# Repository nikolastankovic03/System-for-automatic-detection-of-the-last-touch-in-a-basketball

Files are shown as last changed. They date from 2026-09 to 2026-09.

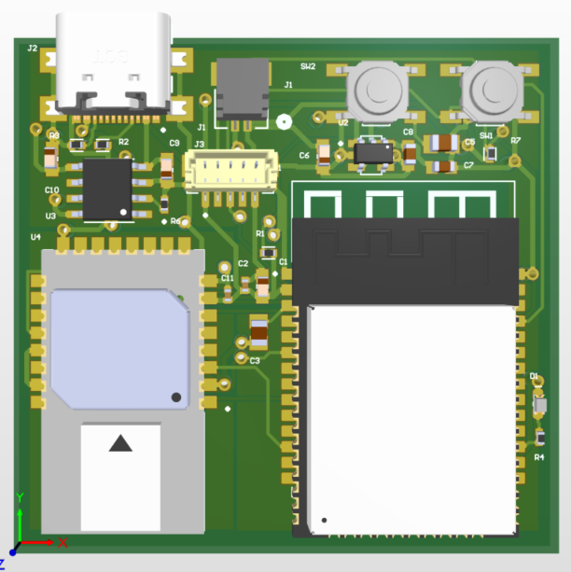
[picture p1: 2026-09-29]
Images/PCB_Player/3Д_Дрес.png

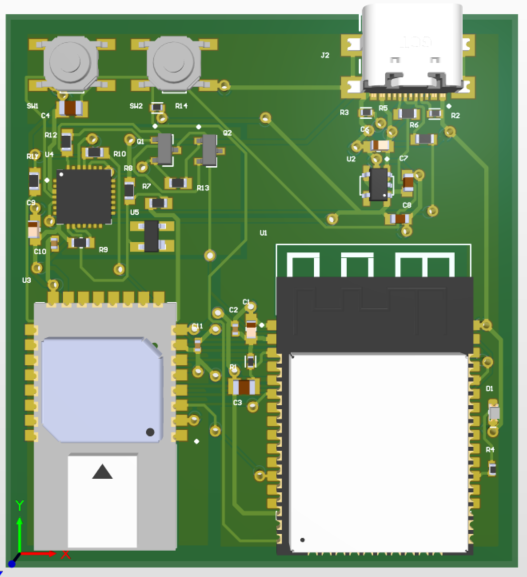
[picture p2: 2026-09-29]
Images/PCB_tabla/3Д_табла.png

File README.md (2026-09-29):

# System-for-automatic-detection-of-the-last-touch-in-a-basketball
The main goal of this work is the design of a system for automatic detection of the last contact with the ball using UWB localization, with precise identification of the player who last touched the ball. The final system architecture includes dedicated printed circuit boards designed for the sensor module inside the ball, the wearable player module, and the stationary module mounted on the backboard structure, while the functionality of the basic algorithms for contact detection, distance measurement, and data transmission was experimentally verified using a laboratory prototype based on available development modules.In addition to the hardware component, a significant part of the work involves the development of a software application for the graphical display and real-time monitoring of events. The application provides an immediate overview of which player, identified by a unique ID, was the last to touch the basketball. The software application consists of a central table displaying all registered contacts, drop-down menus for quick team selection and monitoring of active players, as well as an interactive Start/Stop control system. The Stop button prevents further incoming data from being recorded in the table when the ball leaves the court, thereby preventing irrelevant contacts occurring outside the game from being registered. The Start button reactivates data acquisition when the game resumes.

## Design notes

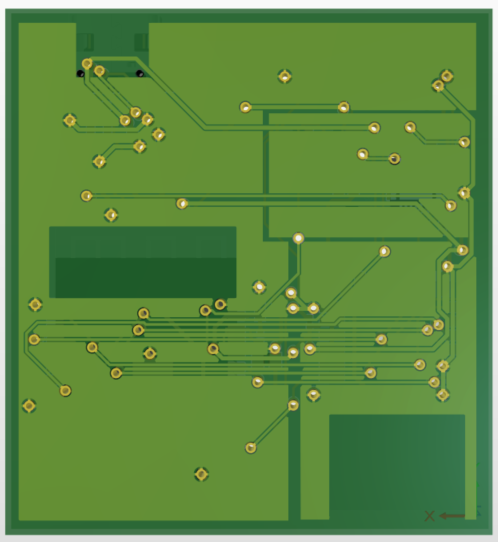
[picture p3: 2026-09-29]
Images/PCB_tabla/3Д_задња_табла.png

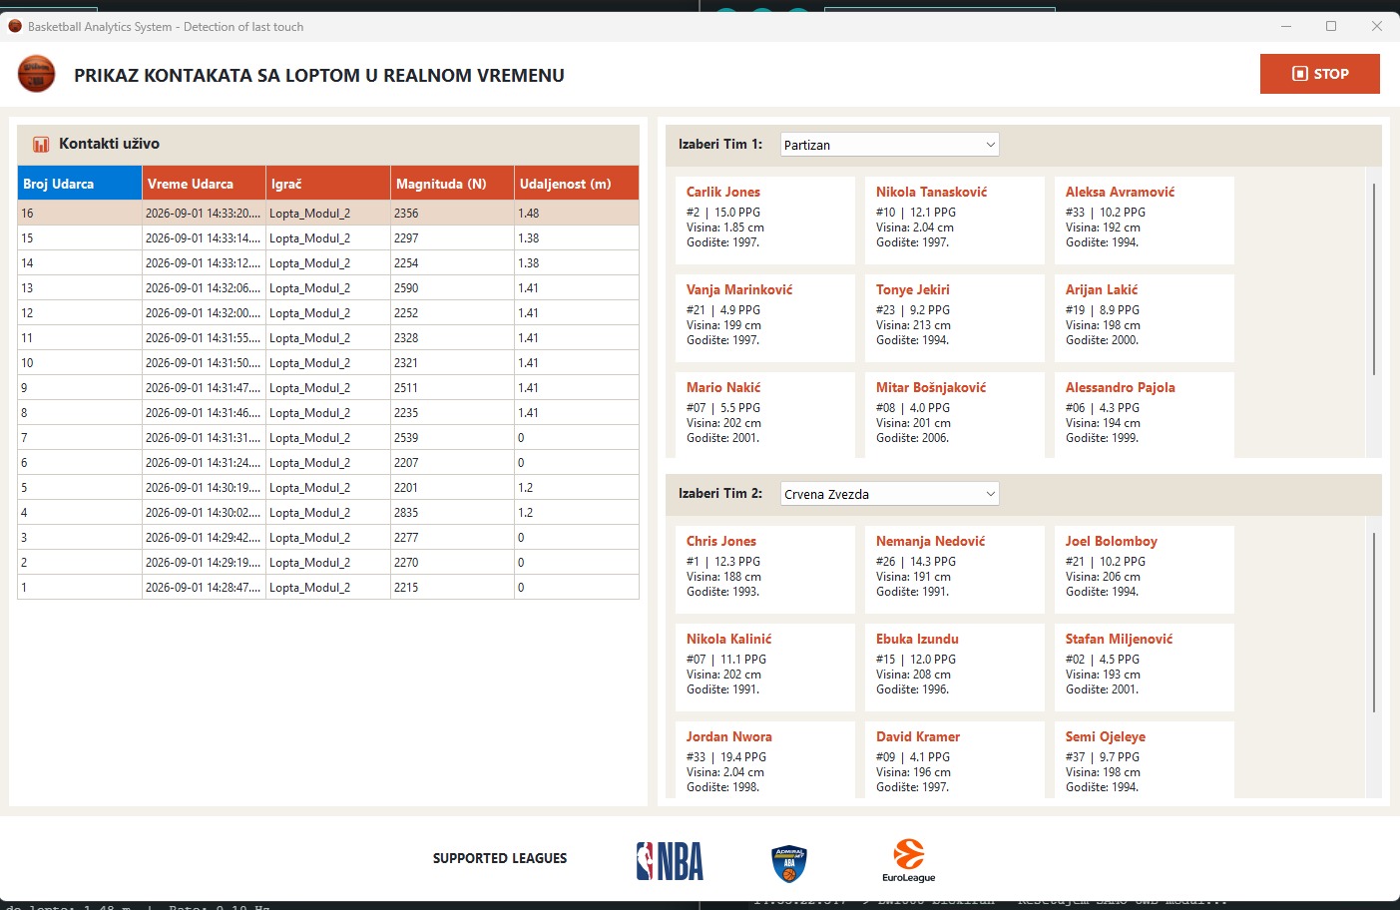
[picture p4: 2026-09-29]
Images/Desktop Aplication/tabela.jpeg

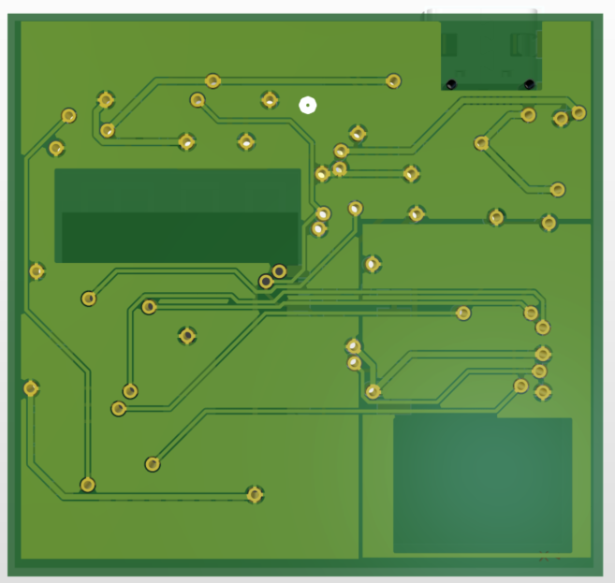
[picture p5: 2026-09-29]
Images/PCB_Player/3Д_Задњастреана_дрес.png

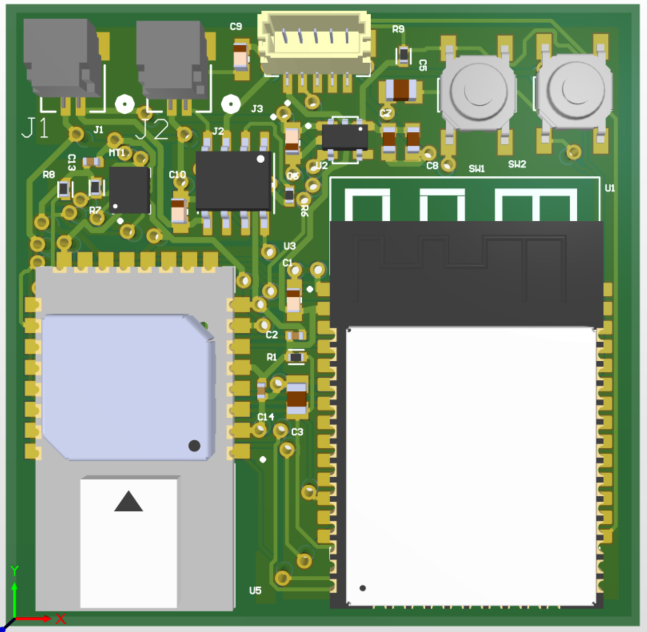
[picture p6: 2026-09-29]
Images/PCB_Ball/3д_лоптапредња_страна.png

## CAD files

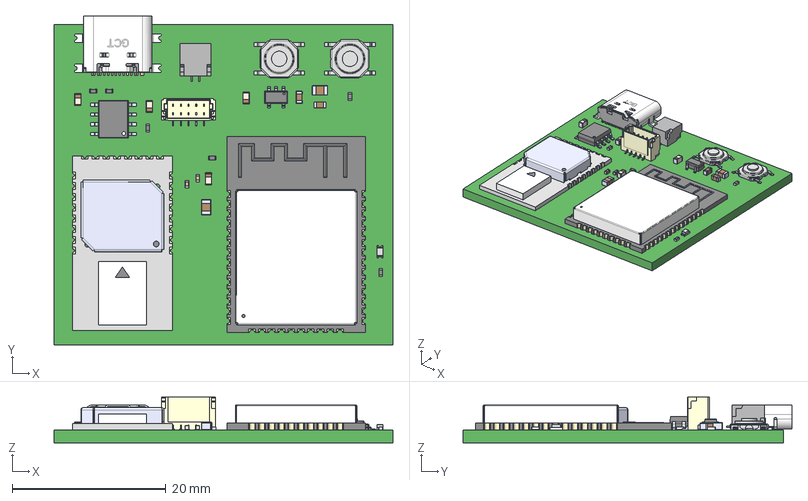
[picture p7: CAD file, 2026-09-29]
PCB_Dres/PCB_Dres.step
44.1 x 42.8 x 5.94 mm
USB4110-GF-A_revB(1) MF
SM02B-SRSS-TB__LF__SN__RGB8421504

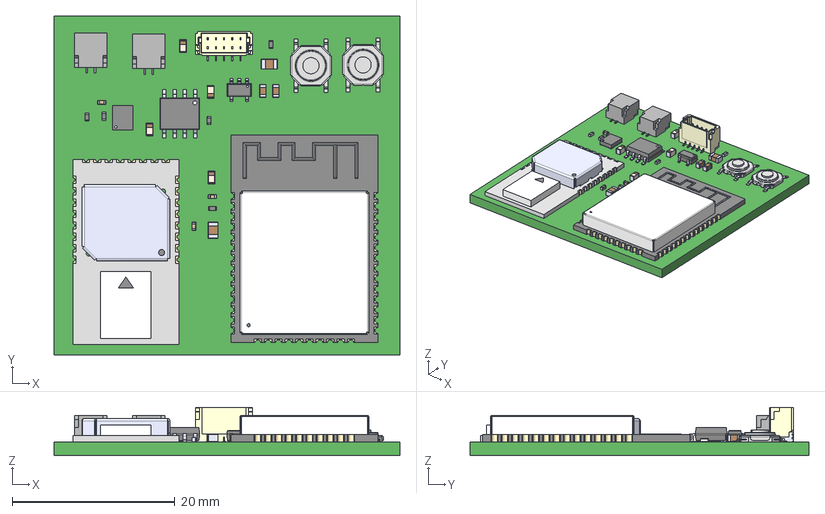
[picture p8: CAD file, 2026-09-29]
PCB_Lopta/PCB_Ball.step
42.4 x 41.6 x 5.94 mm
SM02B-SRSS-TB__LF__SN__RGB8421504 x 2

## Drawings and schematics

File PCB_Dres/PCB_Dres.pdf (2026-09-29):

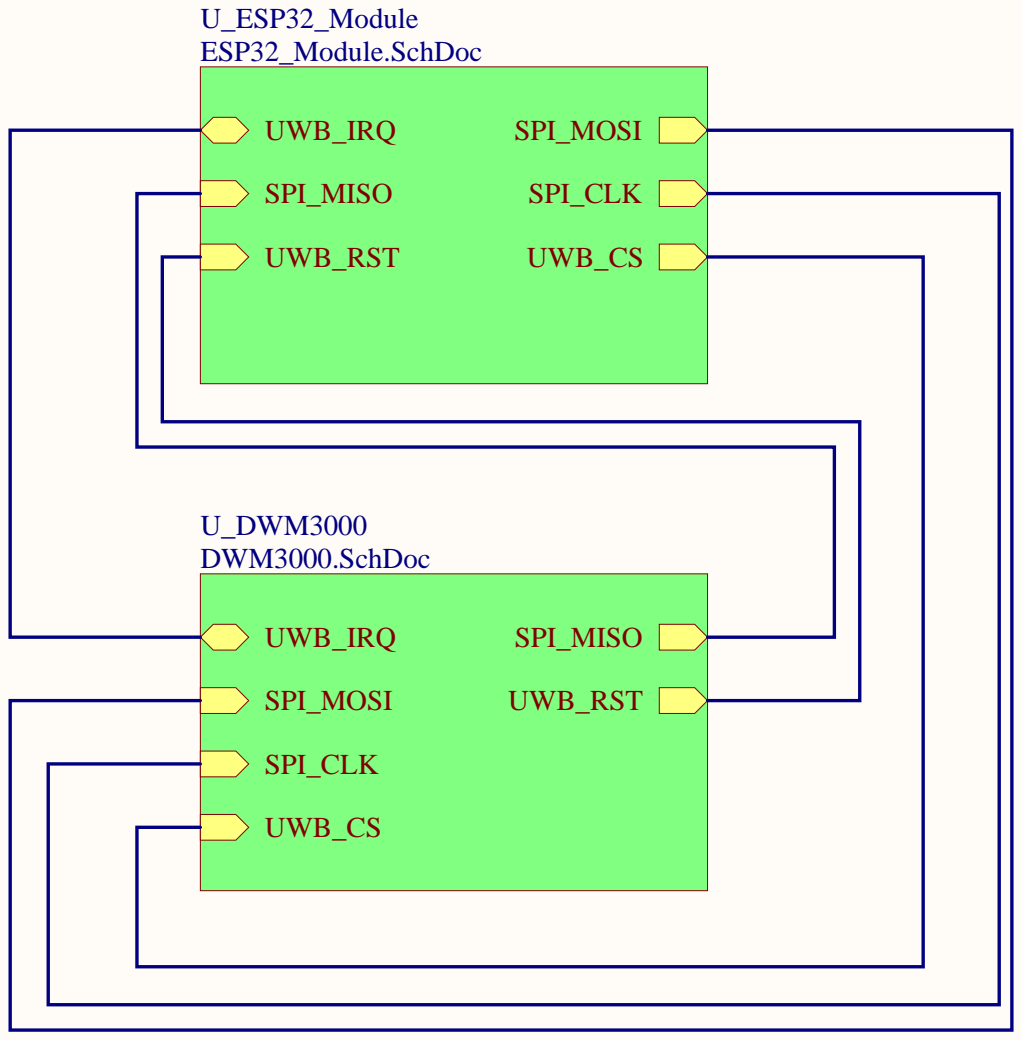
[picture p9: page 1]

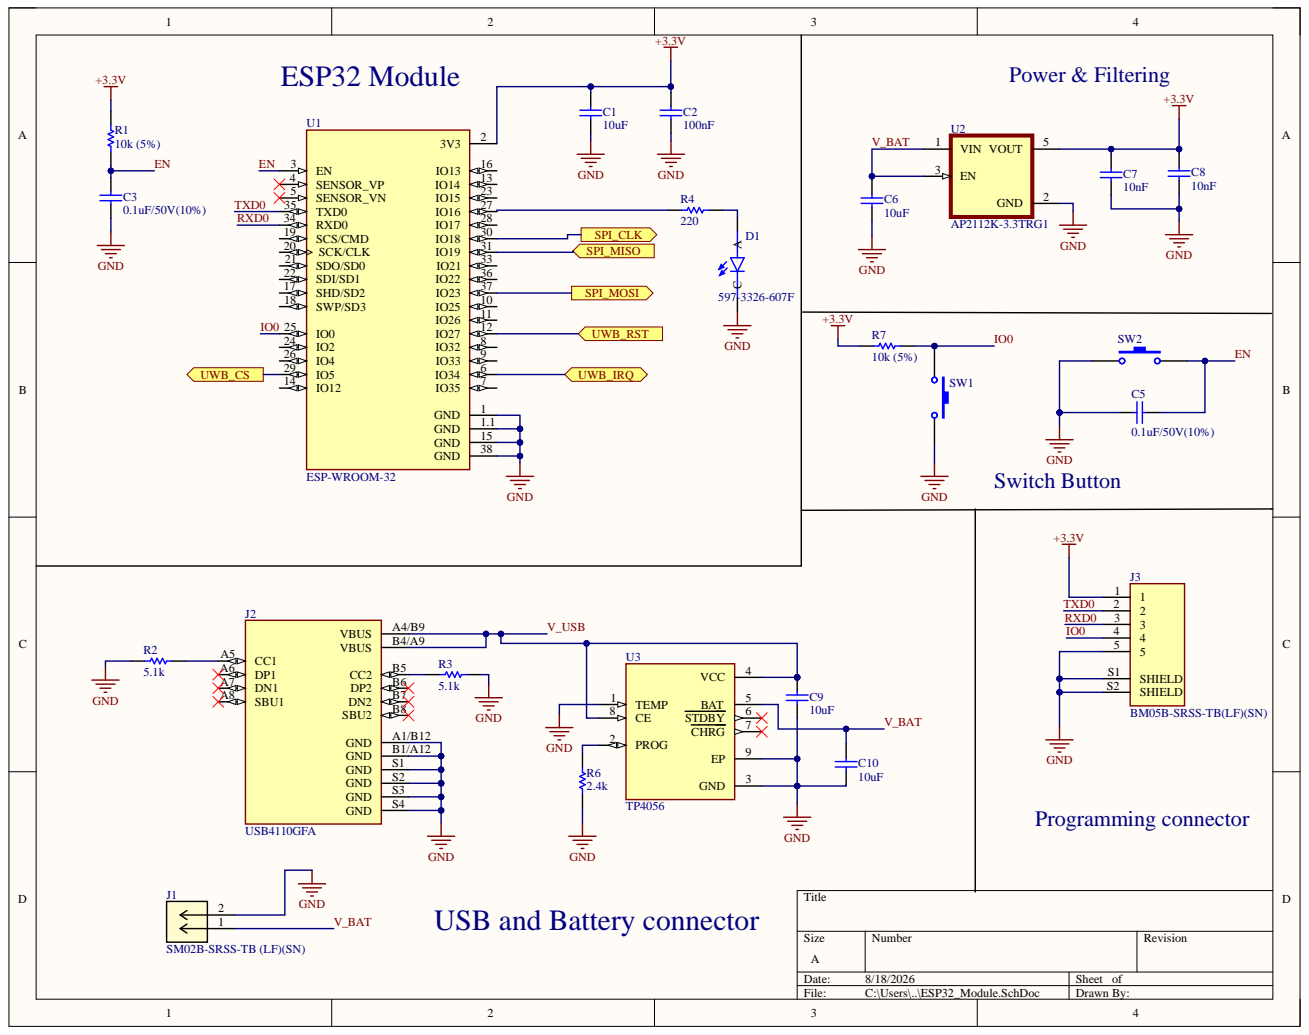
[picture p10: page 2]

BM05B-SRSS-TB(LF)(SN)

USB and Battery connector

SM02B-SRSS-TB (LF)(SN)

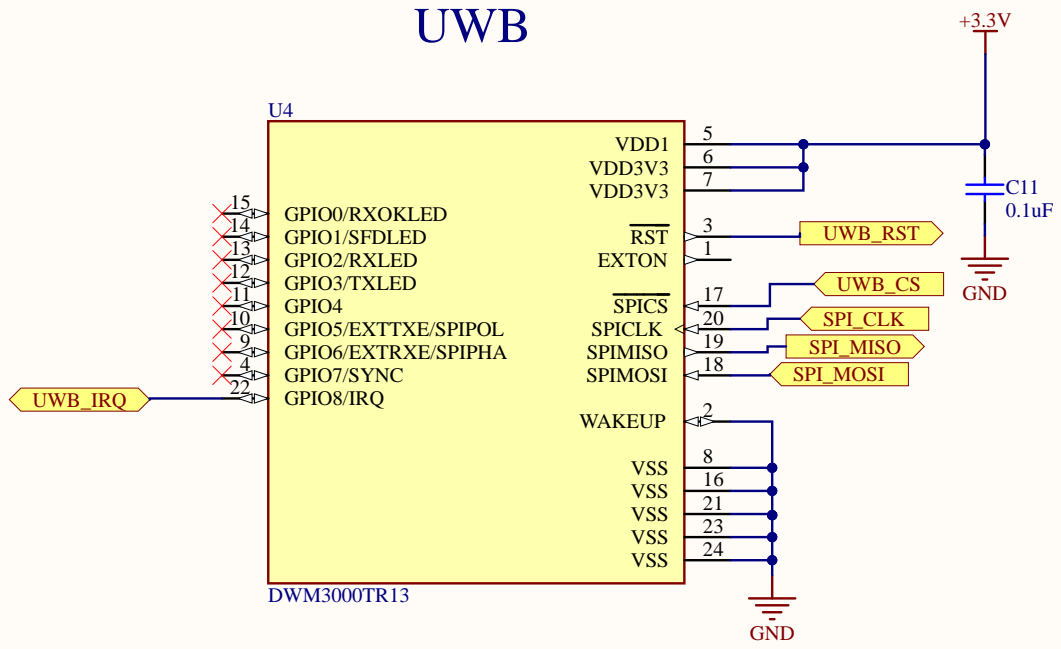
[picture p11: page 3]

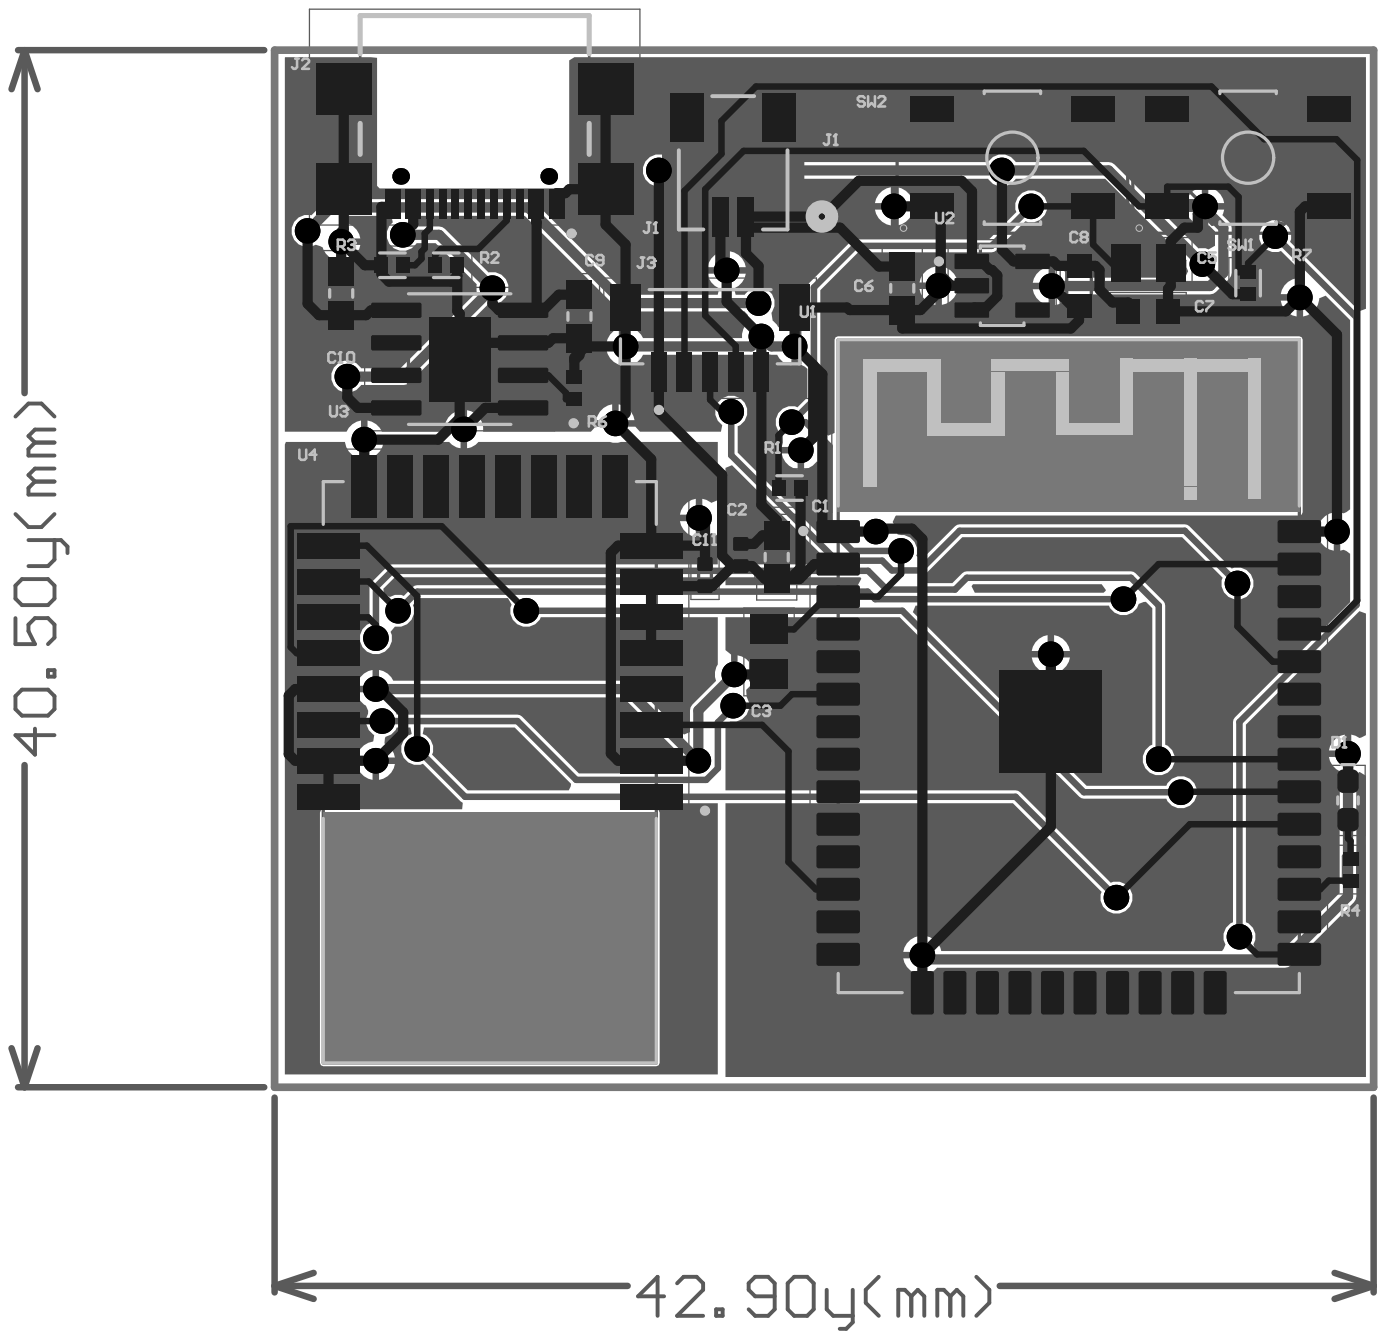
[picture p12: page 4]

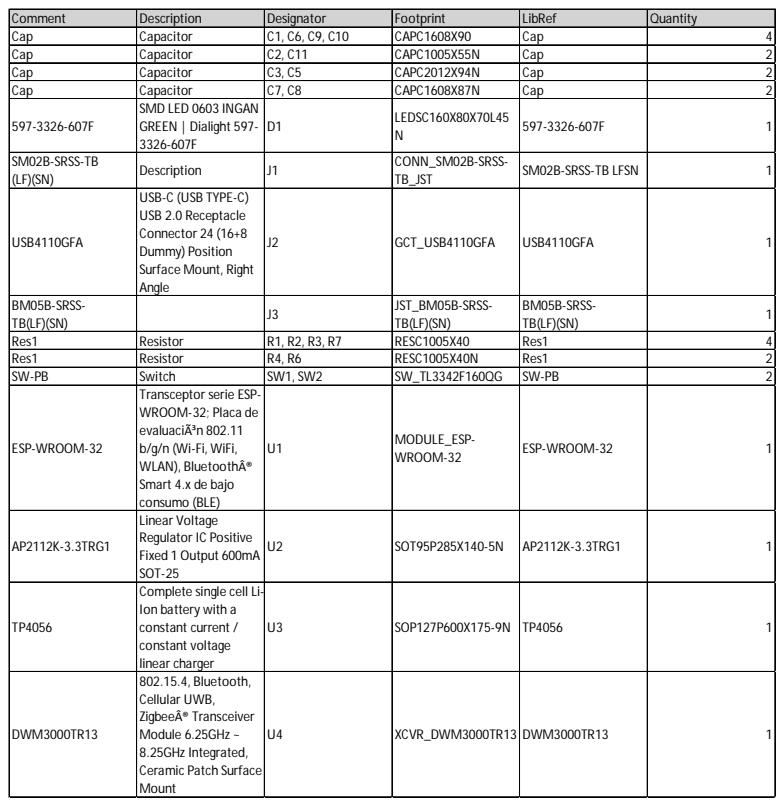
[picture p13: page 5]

Comment | Description | Designator | Footprint | LibRef | Quantity
Cap | Capacitor | C1, C6, C9, C10 | CAPC1608X90 | Cap | 4
Cap | Capacitor | C2, C11 | CAPC1005X55N | Cap | 2
Cap | Capacitor | C3, C5 | CAPC2012X94N | Cap | 2
Cap | Capacitor | C7, C8 | CAPC1608X87N | Cap | 2
597-3326-607F | SMD LED 0603 INGAN GREEN | Dialight 597-3326-607F | D1 | LEDSC160X80X70L45 N | 597-3326-607F | 1

SM02B-SRSS-TB (LF)(SN) | Description | J1 | CONN_SM02B-SRSS-TB_JST | SM02B-SRSS-TB LFSN | 1

USB4110GFA | USB-C (USB TYPE-C) USB 2.0 Receptacle Connector 24 (16+8 Dummy) Position Surface Mount, Right Angle | J2 | GCT_USB4110GFA | USB4110GFA | 1

BM05B-SRSS-TB(LF)(SN) | | J3 | JST_BM05B-SRSS-TB(LF)(SN) | BM05B-SRSS-TB(LF)(SN) | 1

Res1 | Resistor | R1, R2, R3, R7 | RESC1005X40 | Res1 | 4
Res1 | Resistor | R4, R6 | RESC1005X40N | Res1 | 2
SW-PB | Switch | SW1, SW2 | SW_TL3342F160QG | SW-PB | 2
ESP-WROOM-32 | Transceptor serie ESP-WROOM-32; Placa de evaluaciÃ³n 802.11 b/g/n (Wi-Fi, WiFi, WLAN), BluetoothÂ® Smart 4.x de bajo consumo (BLE) | U1 | MODULE_ESP-WROOM-32 | ESP-WROOM-32 | 1

AP2112K-3.3TRG1 | Linear Voltage Regulator IC Positive Fixed 1 Output 600mA SOT-25 | U2 | SOT95P285X140-5N | AP2112K-3.3TRG1 | 1

TP4056 | Complete single cell Li-Ion battery with a constant current / constant voltage linear charger | U3 | SOP127P600X175-9N | TP4056 | 1

DWM3000TR13 | 802.15.4, Bluetooth, Cellular UWB, ZigbeeÂ® Transceiver Module 6.25GHz ~ 8.25GHz Integrated, Ceramic Patch Surface Mount | U4 | XCVR_DWM3000TR13 | DWM3000TR13 | 1

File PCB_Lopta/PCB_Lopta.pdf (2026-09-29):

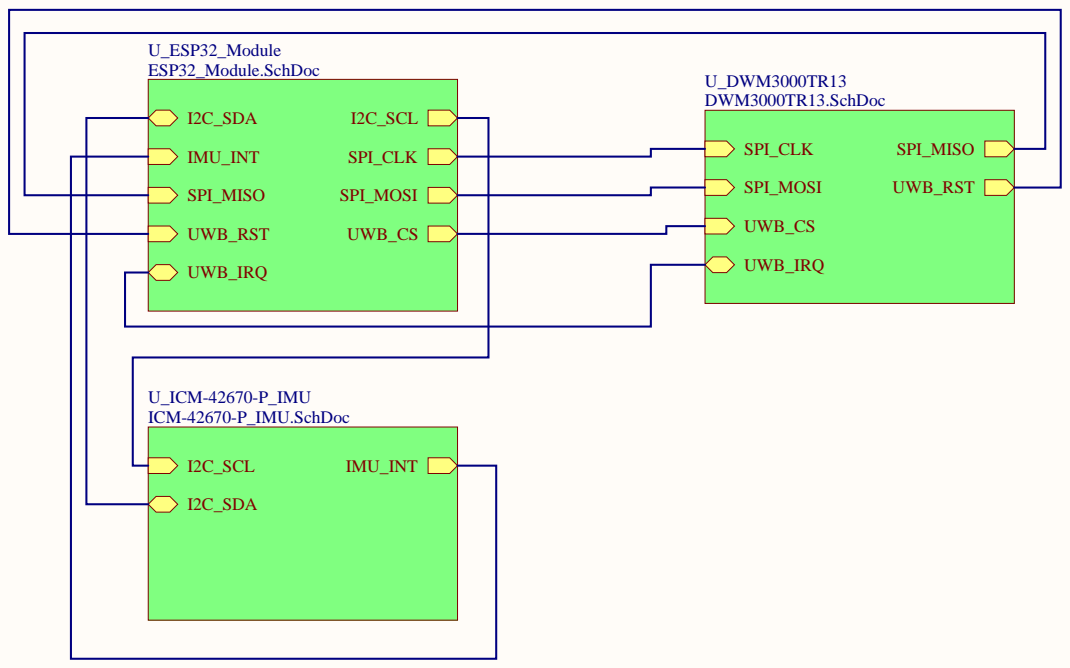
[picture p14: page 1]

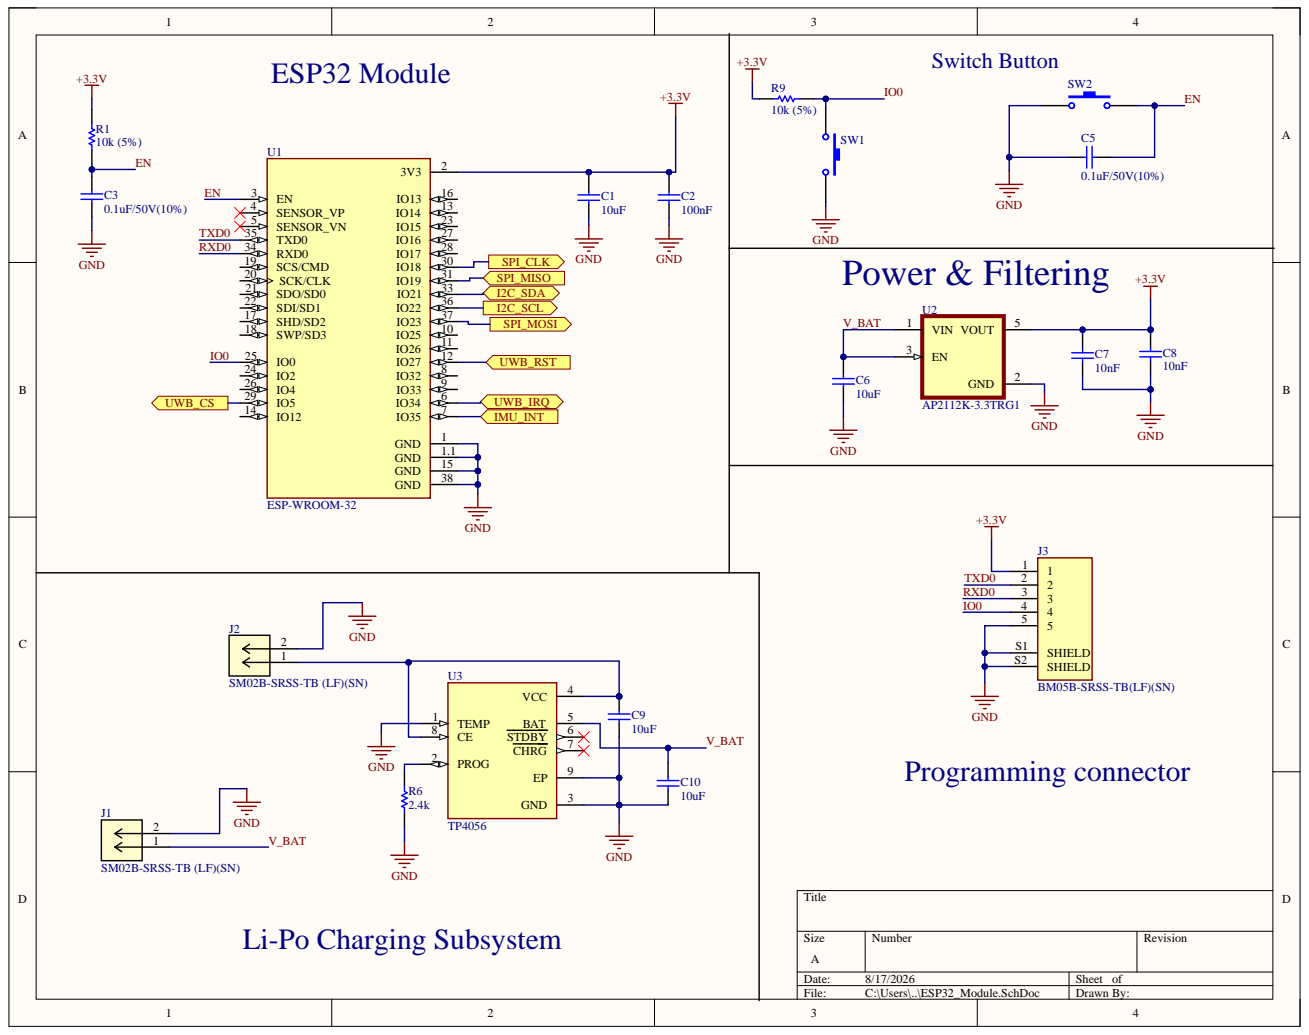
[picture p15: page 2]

SHIELD S1
SHIELD S2

SM02B-SRSS-TB (LF)(SN)

BM05B-SRSS-TB(LF)(SN)

Li-Po Charging Subsystem

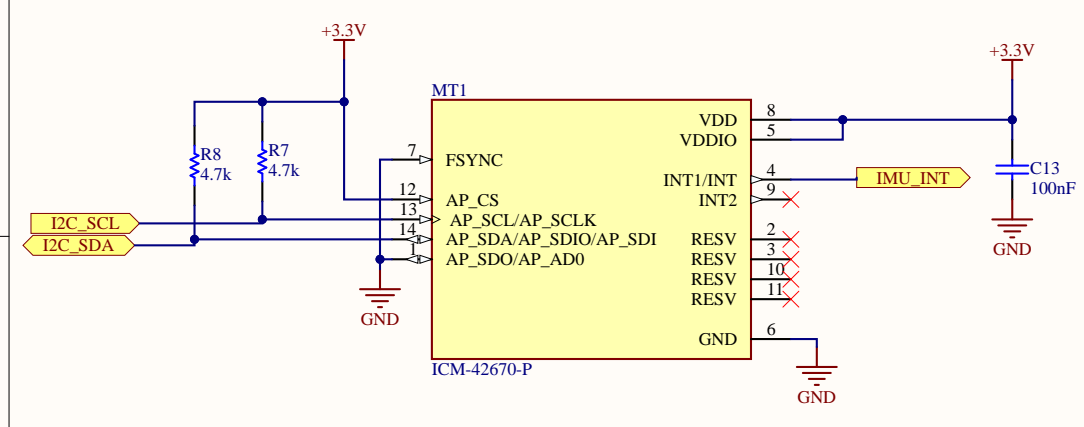
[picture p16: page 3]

AP_CS 12
1 | AP_SCL/AP_SCLK 13 AP_SDA/AP_SDIO/AP_SDI 14

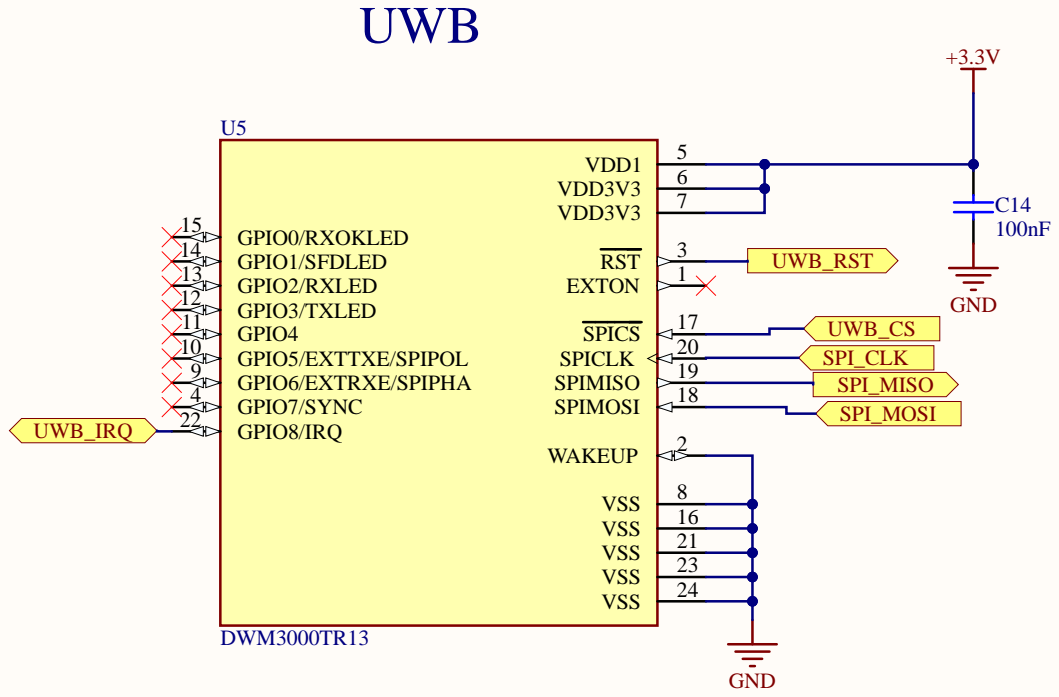
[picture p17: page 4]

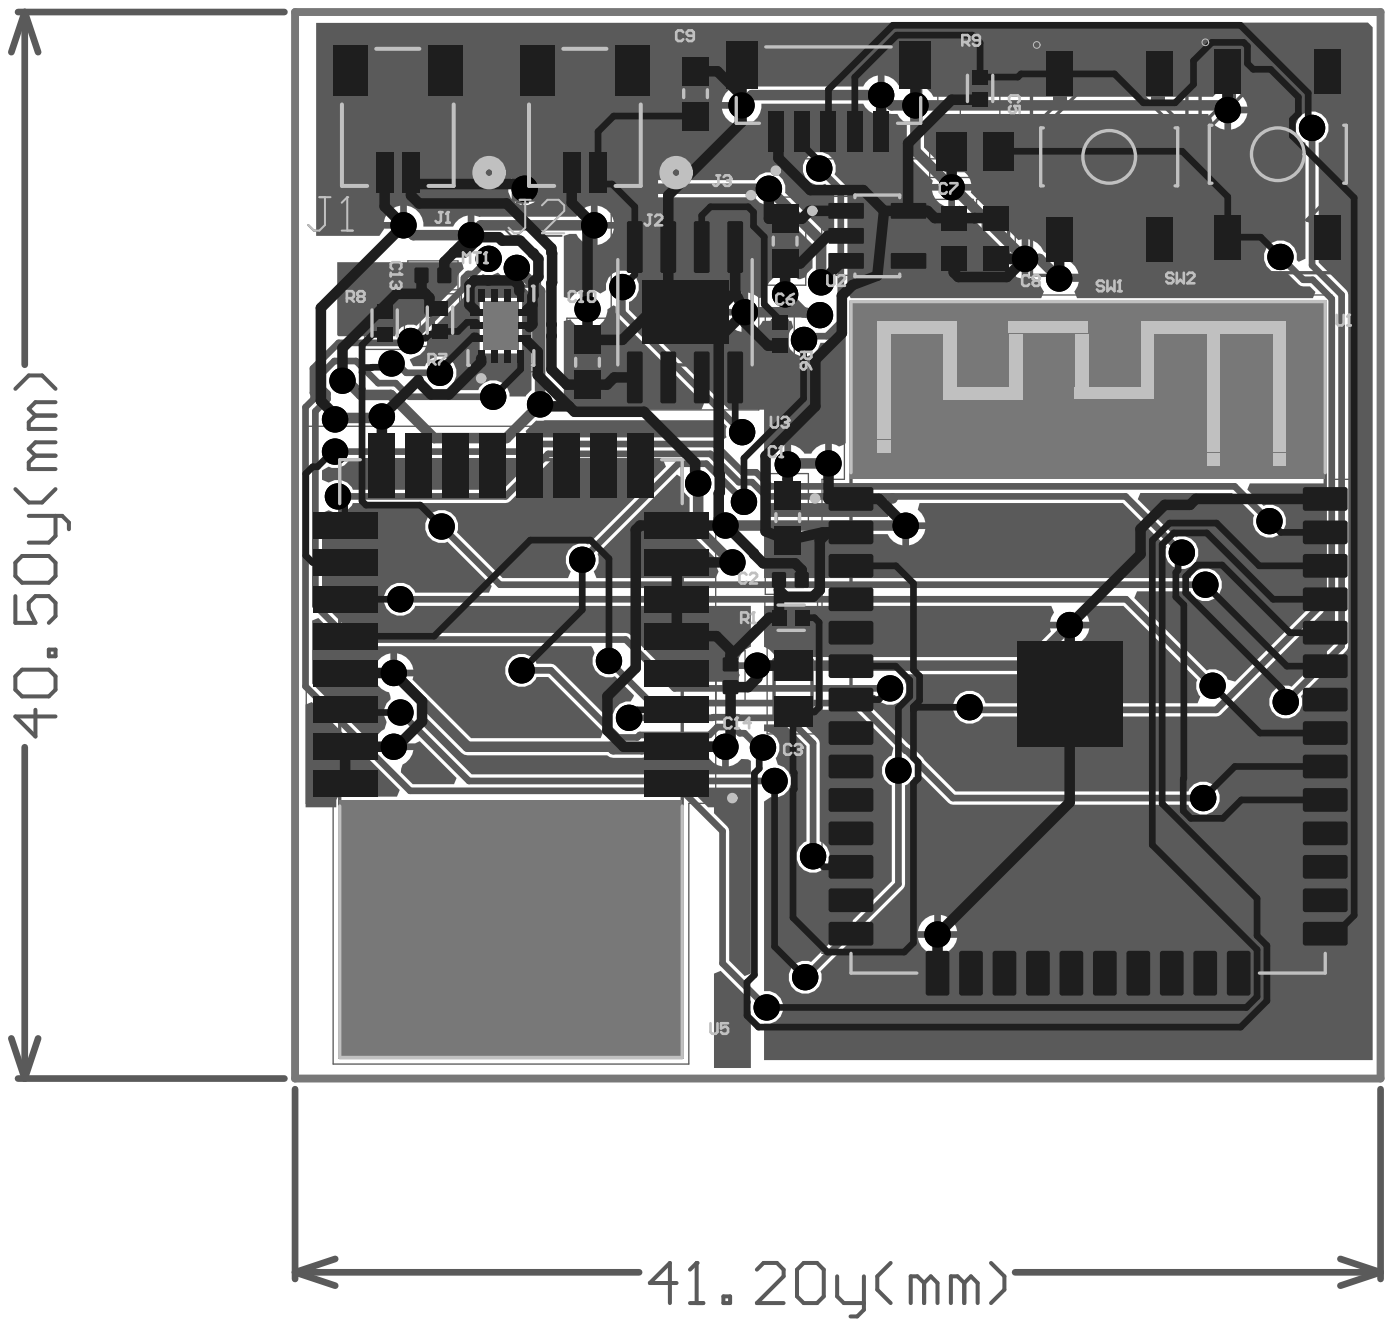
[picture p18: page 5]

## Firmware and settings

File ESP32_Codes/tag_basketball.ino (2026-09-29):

#include <SPI.h>
#include <Wire.h>
#include <WiFi.h>
#include <DW1000.h>
#include <Adafruit_GFX.h>
#include <Adafruit_SH110X.h>
#include <HTTPClient.h>

const char* WIFI_SSID = "XXXXX";
const char* WIFI_PASSWORD = "XXXXXXX";
const char* SERVER_URL = "XXXXXXXXXXXXXXXXXX";
const char* IME_IGRACA = "Lopta_Modul_2";
uint32_t poslednjiPokusajWifi = 0;
const uint32_t WIFI_RETRY_INTERVAL = 10000;

const uint8_t PIN_RST = 4;
const uint8_t PIN_IRQ = 27;
const uint8_t PIN_SS = 5;

#define SCREEN_WIDTH 128
#define SCREEN_HEIGHT 64
Adafruit_SH1106G display(SCREEN_WIDTH, SCREEN_HEIGHT, &Wire, -1);

#define IMU_ADDR 0x68
#define REG_PWR_MGMT0 0x1F
#define REG_ACCEL_DATA_X1 0x0B
#define UDAR_PRAG 2200

#define POLL 0
#define POLL_ACK 1
#define RANGE 2
#define RANGE_REPORT 3
#define RANGE_FAILED 255

volatile byte expectedMsgId = POLL_ACK;
volatile boolean sentAck = false;
volatile boolean receivedAck = false;
volatile byte lastSentMsgId = 255;

DW1000Time timePollSent;
DW1000Time timePollAckReceived;
DW1000Time timeRangeSent;

#define LEN_DATA 16
byte data[LEN_DATA];

uint32_t lastActivity;
uint32_t resetPeriod = 1000;
uint16_t replyDelayTimeUS = 3000;

float lastDistance = 0;
bool haveNewDistance = false;
uint32_t lastPrintTime = 0;
const uint32_t printInterval = 1000;

uint32_t lastOledUpdate = 0;
const uint32_t oledInterval = 200;

uint32_t lastImuRead = 0;
const uint32_t imuInterval = 20;
long zadnjaMagnituda = 0;
int brojUdaraca = 0;

bool udaracUToku = false;
uint32_t vremeZadnjegUdarca = 0;
const uint32_t trajanjeprikazaUdarca = 500;

uint32_t countPollSent = 0;
uint32_t countPollAckRecv = 0;
uint32_t countRangeSent = 0;
uint32_t countRangeReportRecv = 0;
uint32_t countRangeFailedRecv = 0;
uint32_t countProtocolMismatch = 0;
uint32_t countResets = 0;
uint32_t countTransmitCalls = 0;
uint32_t countUnknownMsgId = 0;

void connectWiFi() {
    WiFi.mode(WIFI_STA);
    WiFi.begin(WIFI_SSID, WIFI_PASSWORD);
}

void initUWB() {
    DW1000.begin(PIN_IRQ, PIN_RST);
    DW1000.select(PIN_SS);
    DW1000.newConfiguration();
    DW1000.setDefaults();
    DW1000.setDeviceAddress(2);
    DW1000.setNetworkId(10);
    DW1000.enableMode(DW1000.MODE_LONGDATA_RANGE_LOWPOWER);
    DW1000.commitConfiguration();
    DW1000.attachSentHandler(handleSent);
    DW1000.attachReceivedHandler(handleReceived);
}

void writeRegister(uint8_t reg, uint8_t value) {
    Wire.beginTransmission(IMU_ADDR);
    Wire.write(reg);
    Wire.write(value);
    Wire.endTransmission();
}

void noteActivity() {
    lastActivity = millis();
}

void resetInactive() {
    Serial.println("DW1000 blokiran - Resetujem SAMO UWB modul...");
    countResets++;

    pinMode(PIN_RST, OUTPUT);
    digitalWrite(PIN_RST, LOW);
    delay(10);
    pinMode(PIN_RST, INPUT);
    delay(20);

    initUWB();

    expectedMsgId = POLL_ACK;
    sentAck = false;
    receivedAck = false;

    transmitPoll();
    noteActivity();
}

void posaljiPodatke(long magnituda) {
    if (WiFi.status() != WL_CONNECTED) return;

    detachInterrupt(digitalPinToInterrupt(PIN_IRQ));
    DW1000.idle();

    float slanjeUdaljenosti = haveNewDistance ? lastDistance : 0.0;

    HTTPClient http;
    http.begin(SERVER_URL);
    http.addHeader("Content-Type", "application/json");
    http.setTimeout(1500); 
    
    String jsonPayload = "{\"igrac\":\"" + String(IME_IGRACA) +
                          "\",\"magnituda\":" + String(magnituda) +
                          ",\"udaljenost\":" + String(slanjeUdaljenosti, 2) + "}";
    http.POST(jsonPayload);
    http.end();

    resetInactive();
}

void setup() {
    Serial.begin(115200);
    delay(1000);

    Wire.begin(21, 22);
    delay(100);
    if (!display.begin(0x3C, true)) {
        Serial.println("OLED nije pronadjen!");
    }
    display.clearDisplay();
    display.setTextColor(SH110X_WHITE);
    display.setTextSize(1);
    display.setCursor(0, 0);
    display.println("Inicijalizacija...");
    display.display();

    writeRegister(REG_PWR_MGMT0, 0x0F);
    delay(100);

    connectWiFi();

    SPI.begin(18, 19, 23, 5);
    SPI.setFrequency(4000000);
    delay(500);

    Serial.println(F("### DW1000-arduino-ranging-tag sa OLED i IMU ###"));

    initUWB();
    Serial.println(F("Committed configuration ..."));

    transmitPoll();
    noteActivity();
    lastPrintTime = millis();

    display.clearDisplay();
    display.setCursor(0, 0);
    display.println("Spreman.");
    display.display();
}

void handleSent() {
    sentAck = true;
    lastSentMsgId = data[0];
}

void handleReceived() {
    receivedAck = true;
}

void transmitPoll() {
    countTransmitCalls++;
    DW1000.idle();
    DW1000.newTransmit();
    DW1000.setDefaults();
    data[0] = POLL;
    DW1000.setData(data, LEN_DATA);
    DW1000.startTransmit();
}

void transmitRange() {
    DW1000.idle();
    DW1000.newTransmit();
    DW1000.setDefaults();
    data[0] = RANGE;
    DW1000Time deltaTime = DW1000Time(replyDelayTimeUS, DW1000Time::MICROSECONDS);
    timeRangeSent = DW1000.setDelay(deltaTime);
    timePollSent.getTimestamp(data + 1);
    timePollAckReceived.getTimestamp(data + 6);
    timeRangeSent.getTimestamp(data + 11);
    DW1000.setData(data, LEN_DATA);
    DW1000.startTransmit();
}

void receiver() {
    DW1000.idle();
    DW1000.newReceive();
    DW1000.setDefaults();
    DW1000.receivePermanently(true);
    DW1000.startReceive();
}

void updateImu() {
    Wire.beginTransmission(IMU_ADDR);
    Wire.write(REG_ACCEL_DATA_X1);
    Wire.endTransmission(false);
    Wire.requestFrom(IMU_ADDR, 6);

    if (Wire.available() == 6) {
        int16_t ax = (Wire.read() << 8) | Wire.read();
        int16_t ay = (Wire.read() << 8) | Wire.read();
        int16_t az = (Wire.read() << 8) | Wire.read();

        if (abs(az) >= 500) {
            zadnjaMagnituda = abs(ax) + abs(ay) + abs(az);
            bool sadaPrekoraceno = zadnjaMagnituda > UDAR_PRAG;

            if (sadaPrekoraceno && !udaracUToku) {
                brojUdaraca++;
                vremeZadnjegUdarca = millis();
                Serial.print("Detektovan udarac! Mag: ");
                Serial.println(zadnjaMagnituda);
                
                posaljiPodatke(zadnjaMagnituda);
            }
            udaracUToku = sadaPrekoraceno;
        } else {
            udaracUToku = false;
        }
    }
}

void updateOled() {
    display.clearDisplay();
    display.setTextSize(1);
    display.setCursor(0, 0);
    display.println("Status lopte:");

    display.setCursor(0, 12);
    display.setTextSize(2);
    if (millis() - vremeZadnjegUdarca < trajanjeprikazaUdarca) {
        display.println("UDARAC!");
    } else {
        display.println("Mirovanje");
    }

    display.setTextSize(1);
    display.setCursor(0, 32);
    display.print("Mag: ");
    display.println(zadnjaMagnituda);

    display.setCursor(0, 44);
    display.print("Udaljenost: ");
    if (haveNewDistance) {
        display.print(lastDistance, 2);
        display.println(" m");
    } else {
        display.println("N/A");
    }

    display.setCursor(0, 56);
    display.print("Broj udaraca: ");
    display.println(brojUdaraca);

    display.display();
}

void loop() {
    uint32_t curMillis = millis();

    if (sentAck) {
        sentAck = false;
        if (lastSentMsgId == POLL) {
            DW1000.getTransmitTimestamp(timePollSent);
            countPollSent++;
            receiver();
        } else if (lastSentMsgId == RANGE) {
            DW1000.getTransmitTimestamp(timeRangeSent);
            countRangeSent++;
            noteActivity();
            receiver();
        }
    }

    if (receivedAck) {
        receivedAck = false;
        DW1000.getData(data, LEN_DATA);
        byte msgId = data[0];

        if (msgId != expectedMsgId) {
            countProtocolMismatch++;
            expectedMsgId = POLL_ACK;
            transmitPoll();
        } else if (msgId == POLL_ACK) {
            countPollAckRecv++;
            DW1000.getReceiveTimestamp(timePollAckReceived);
            expectedMsgId = RANGE_REPORT;
            transmitRange();
            noteActivity();
        } else if (msgId == RANGE_REPORT) {
            countRangeReportRecv++;
            expectedMsgId = POLL_ACK;
            float curRange;
            memcpy(&curRange, data + 1, 4);

            lastDistance = curRange;
            haveNewDistance = true;
            transmitPoll();
            noteActivity();
        } else if (msgId == RANGE_FAILED) {
            countRangeFailedRecv++;
            expectedMsgId = POLL_ACK;
            transmitPoll();
            noteActivity();
        } else {
            countUnknownMsgId++;
        }
    }

    if (!sentAck && !receivedAck) {
        if (curMillis - lastActivity > resetPeriod) {
            resetInactive();
        }
    }

    if (curMillis - lastPrintTime >= printInterval) {
        lastPrintTime = curMillis;
        Serial.print("Dist: "); Serial.print(lastDistance);
        Serial.print(" m | PollSent:"); Serial.print(countPollSent);
        Serial.print(" PollAckRecv:"); Serial.print(countPollAckRecv);
        Serial.print(" RangeSent:"); Serial.print(countRangeSent);
        Serial.print(" ReportRecv:"); Serial.print(countRangeReportRecv);
        Serial.print(" Failed:"); Serial.print(countRangeFailedRecv);
        Serial.print(" Mismatch:"); Serial.print(countProtocolMismatch);
        Serial.print(" Unknown:"); Serial.print(countUnknownMsgId);
        Serial.print(" Resets:"); Serial.println(countResets);
    }

    if (curMillis - lastImuRead >= imuInterval) {
        lastImuRead = curMillis;
        updateImu();
    }

    if (curMillis - lastOledUpdate >= oledInterval) {
        lastOledUpdate = curMillis;
        updateOled();
    }

    if (WiFi.status() != WL_CONNECTED && curMillis - poslednjiPokusajWifi > WIFI_RETRY_INTERVAL) {
        poslednjiPokusajWifi = curMillis;
        connectWiFi();
    }

    delay(2);
}

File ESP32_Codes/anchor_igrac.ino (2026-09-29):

#include <SPI.h>
#include <WiFi.h>
#include <DW1000.h>

const uint8_t PIN_RST = 4;
const uint8_t PIN_IRQ = 27;
const uint8_t PIN_SS = 5;

#define POLL 0
#define POLL_ACK 1
#define RANGE 2
#define RANGE_REPORT 3
#define RANGE_FAILED 255

volatile byte expectedMsgId = POLL;
volatile boolean sentAck = false;
volatile boolean receivedAck = false;
volatile byte lastSentMsgId = 255;
boolean protocolFailed = false;

DW1000Time timePollSent;
DW1000Time timePollReceived;
DW1000Time timePollAckSent;
DW1000Time timePollAckReceived;
DW1000Time timeRangeSent;
DW1000Time timeRangeReceived;
DW1000Time timeComputedRange;

#define LEN_DATA 16
byte data[LEN_DATA];

uint32_t lastActivity;
uint32_t resetPeriod = 250;
uint16_t replyDelayTimeUS = 3000;
uint16_t successRangingCount = 0;
uint32_t rangingCountPeriod = 0;
float samplingRate = 0;

float lastDistance = 0;
bool haveNewDistance = false;
uint32_t lastPrintTime = 0;
const uint32_t printInterval = 1000;

void setup() {
    Serial.begin(115200);
    delay(1000);

    WiFi.mode(WIFI_OFF);
    SPI.begin(18, 19, 23, 5);
    delay(500);

    Serial.println(F("### DW1000-arduino-ranging-anchor ###"));

    DW1000.begin(PIN_IRQ, PIN_RST);
    DW1000.select(PIN_SS);
    Serial.println(F("DW1000 initialized ..."));

    DW1000.newConfiguration();
    DW1000.setDefaults();
    DW1000.setDeviceAddress(1);
    DW1000.setNetworkId(10);
    DW1000.enableMode(DW1000.MODE_LONGDATA_RANGE_LOWPOWER);
    DW1000.commitConfiguration();
    Serial.println(F("Committed configuration ..."));

    DW1000.attachSentHandler(handleSent);
    DW1000.attachReceivedHandler(handleReceived);

    receiver();
    noteActivity();
    rangingCountPeriod = millis();
    lastPrintTime = millis();
}

void noteActivity() {
    lastActivity = millis();
}

void resetInactive() {
    expectedMsgId = POLL;
    receiver();
    noteActivity();
}

void handleSent() {
    sentAck = true;
    lastSentMsgId = data[0];
}

void handleReceived() {
    receivedAck = true;
}

void transmitPollAck() {
    DW1000.newTransmit();
    DW1000.setDefaults();
    data[0] = POLL_ACK;
    DW1000Time deltaTime = DW1000Time(replyDelayTimeUS, DW1000Time::MICROSECONDS);
    DW1000.setDelay(deltaTime);
    DW1000.setData(data, LEN_DATA);
    DW1000.startTransmit();
}

void transmitRangeReport(float curRange) {
    DW1000.newTransmit();
    DW1000.setDefaults();
    data[0] = RANGE_REPORT;
    memcpy(data + 1, &curRange, 4);
    DW1000.setData(data, LEN_DATA);
    DW1000.startTransmit();
}

void transmitRangeFailed() {
    DW1000.newTransmit();
    DW1000.setDefaults();
    data[0] = RANGE_FAILED;
    DW1000.setData(data, LEN_DATA);
    DW1000.startTransmit();
}

void receiver() {
    DW1000.newReceive();
    DW1000.setDefaults();
    DW1000.receivePermanently(true);
    DW1000.startReceive();
}

void computeRangeAsymmetric() {
    DW1000Time round1 = (timePollAckReceived - timePollSent).wrap();
    DW1000Time reply1 = (timePollAckSent - timePollReceived).wrap();
    DW1000Time round2 = (timeRangeReceived - timePollAckSent).wrap();
    DW1000Time reply2 = (timeRangeSent - timePollAckReceived).wrap();

    DW1000Time denom = round1 + round2 + reply1 + reply2;
    if (denom.getAsMicroSeconds() == 0) {
        timeComputedRange.setTimestamp((int64_t)0);
        return;
    }

    DW1000Time tof = (round1 * round2 - reply1 * reply2) / denom;
    timeComputedRange.setTimestamp(tof);
}

void loop() {
    int32_t curMillis = millis();

    if (sentAck) {
        sentAck = false;
        if (lastSentMsgId == POLL_ACK) {
            DW1000.getTransmitTimestamp(timePollAckSent);
            noteActivity();
        }
    }

    if (receivedAck) {
        receivedAck = false;
        DW1000.getData(data, LEN_DATA);
        byte msgId = data[0];
        if (msgId != expectedMsgId) {
            protocolFailed = true;
        }
        if (msgId == POLL) {
            protocolFailed = false;
            DW1000.getReceiveTimestamp(timePollReceived);
            expectedMsgId = RANGE;
            transmitPollAck();
            noteActivity();
        }
        else if (msgId == RANGE) {
            DW1000.getReceiveTimestamp(timeRangeReceived);
            expectedMsgId = POLL;
            if (!protocolFailed) {
                timePollSent.setTimestamp(data + 1);
                timePollAckReceived.setTimestamp(data + 6);
                timeRangeSent.setTimestamp(data + 11);
                computeRangeAsymmetric();

                // FIX: salji metre, ne mikrosekunde - tag ocekuje vec konvertovanu vrednost
                float distanceMeters = timeComputedRange.getAsMeters();
                transmitRangeReport(distanceMeters);

                lastDistance = distanceMeters;
                haveNewDistance = true;

                successRangingCount++;
                if (curMillis - rangingCountPeriod > 1000) {
                    samplingRate = (1000.0f * successRangingCount) / (curMillis - rangingCountPeriod);
                    rangingCountPeriod = curMillis;
                    successRangingCount = 0;
                }
            } else {
                transmitRangeFailed();
            }
            noteActivity();
        }
    }

    if (!sentAck && !receivedAck) {
        if (curMillis - lastActivity > resetPeriod) {
            resetInactive();
        }
    }

    if (curMillis - lastPrintTime >= printInterval) {
        lastPrintTime = curMillis;
        if (haveNewDistance) {
            Serial.print("Udaljenost do lopte: ");
            Serial.print(lastDistance);
            Serial.print(" m  |  Rate: ");
            Serial.print(samplingRate);
            Serial.println(" Hz");
        } else {
            Serial.println("Nema jos merenja...");
        }
    }

    delay(2);
}
